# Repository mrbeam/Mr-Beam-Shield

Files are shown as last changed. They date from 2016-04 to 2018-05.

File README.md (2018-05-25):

# README #

### Mr Beam Shield ###

* The Mr Beam Shield is a grbl compatible Arduino Shield which combines 3 stepper motor driver sockets (pololu/stepstick compatible) with a laser diode driver 
* Version 1.1
* 

### How do I get set up? ###

* See manual.pdf in this repository for a detailed description of the shield.

### Who do I talk to? ###

* The Mr Beam Shield was developed for the Mr Beam Laser Cutter Kit, published on Kickstarter May 2014
* get in touch for any purpose: support@mr-beam.org

### LICENSE ###
This work is licensed under the Creative Commons Attribution-NonCommercial-ShareAlike 4.0 International License. 
To view a copy of this license, visit http://creativecommons.org/licenses/by-nc-sa/4.0/.

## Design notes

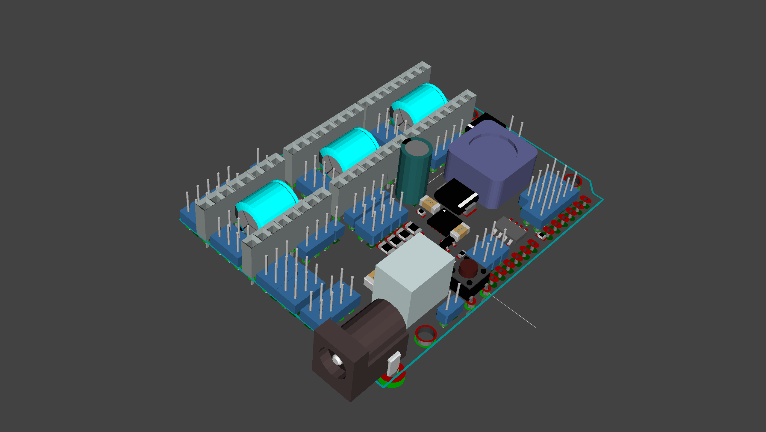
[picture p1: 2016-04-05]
MrBeamShield/MrBeamShield2.png

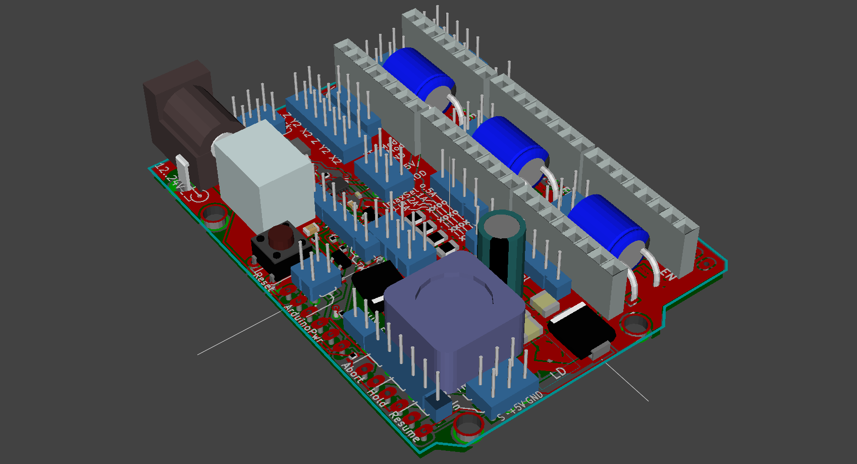
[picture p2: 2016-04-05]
MrBeamShield/MrBeamShield_coil.png

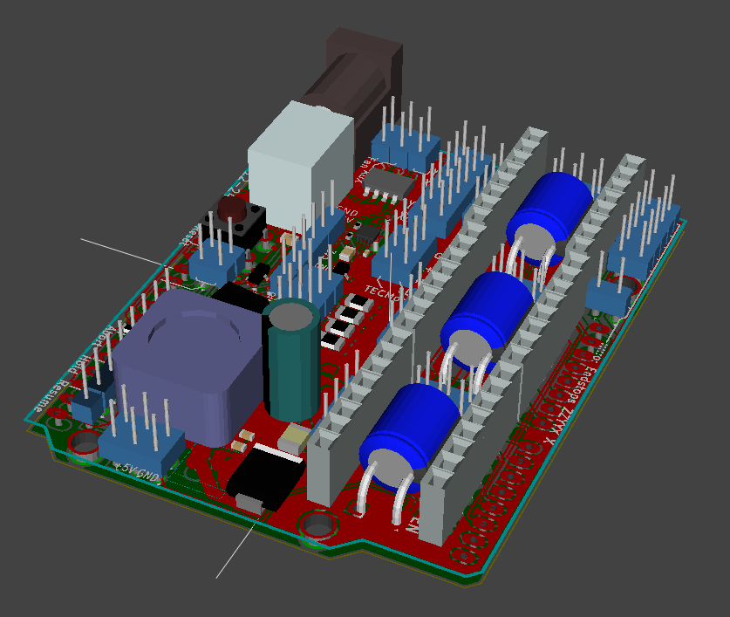
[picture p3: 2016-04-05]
MrBeamShield/MrBeamShield.png

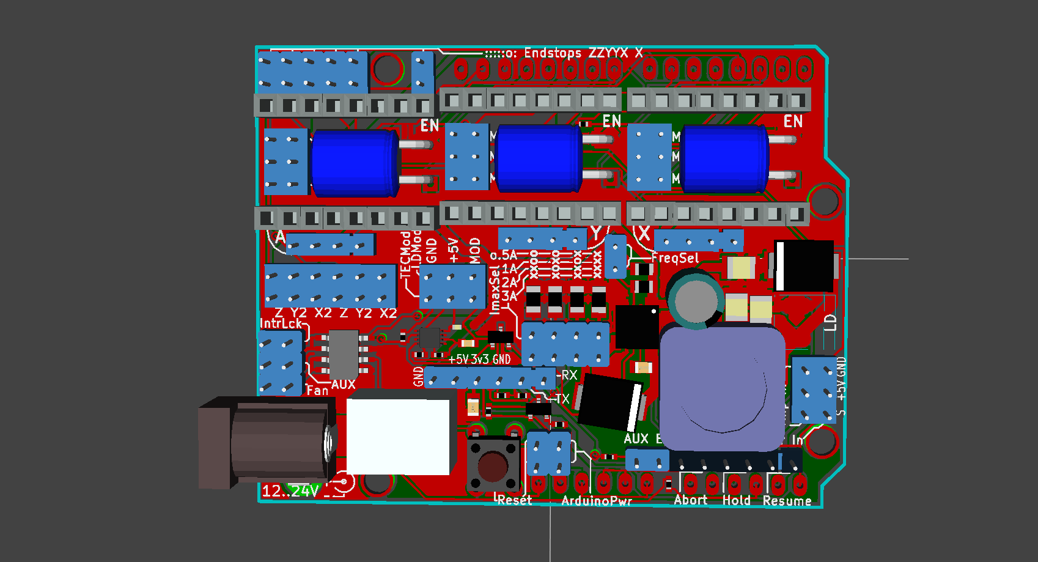
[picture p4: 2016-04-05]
MrBeamShield/MrBeamShield_top.png

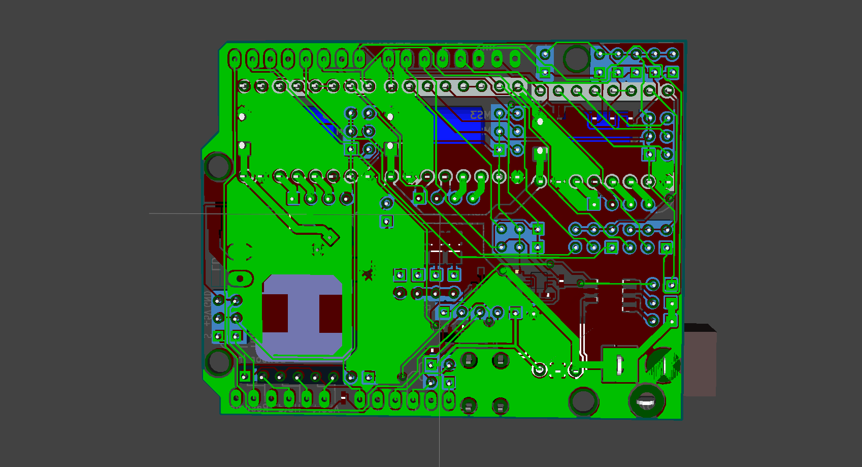
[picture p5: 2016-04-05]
MrBeamShield/MrBeamShield_bottom.png

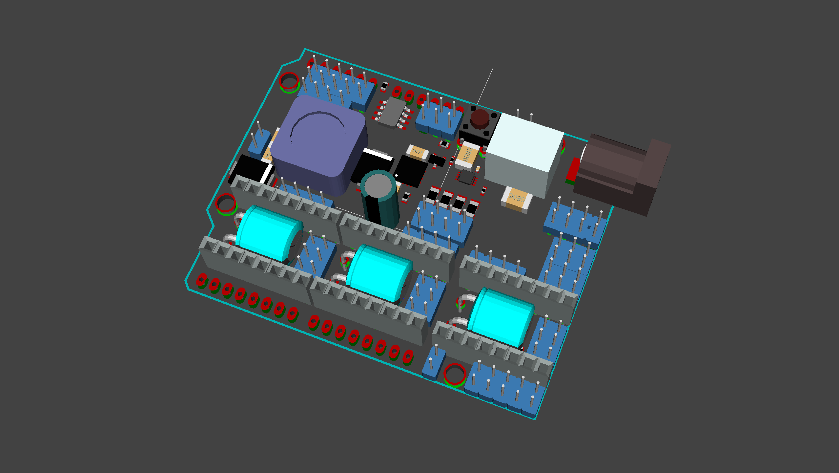
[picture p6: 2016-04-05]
MrBeamShield/MrBeamShield3.png

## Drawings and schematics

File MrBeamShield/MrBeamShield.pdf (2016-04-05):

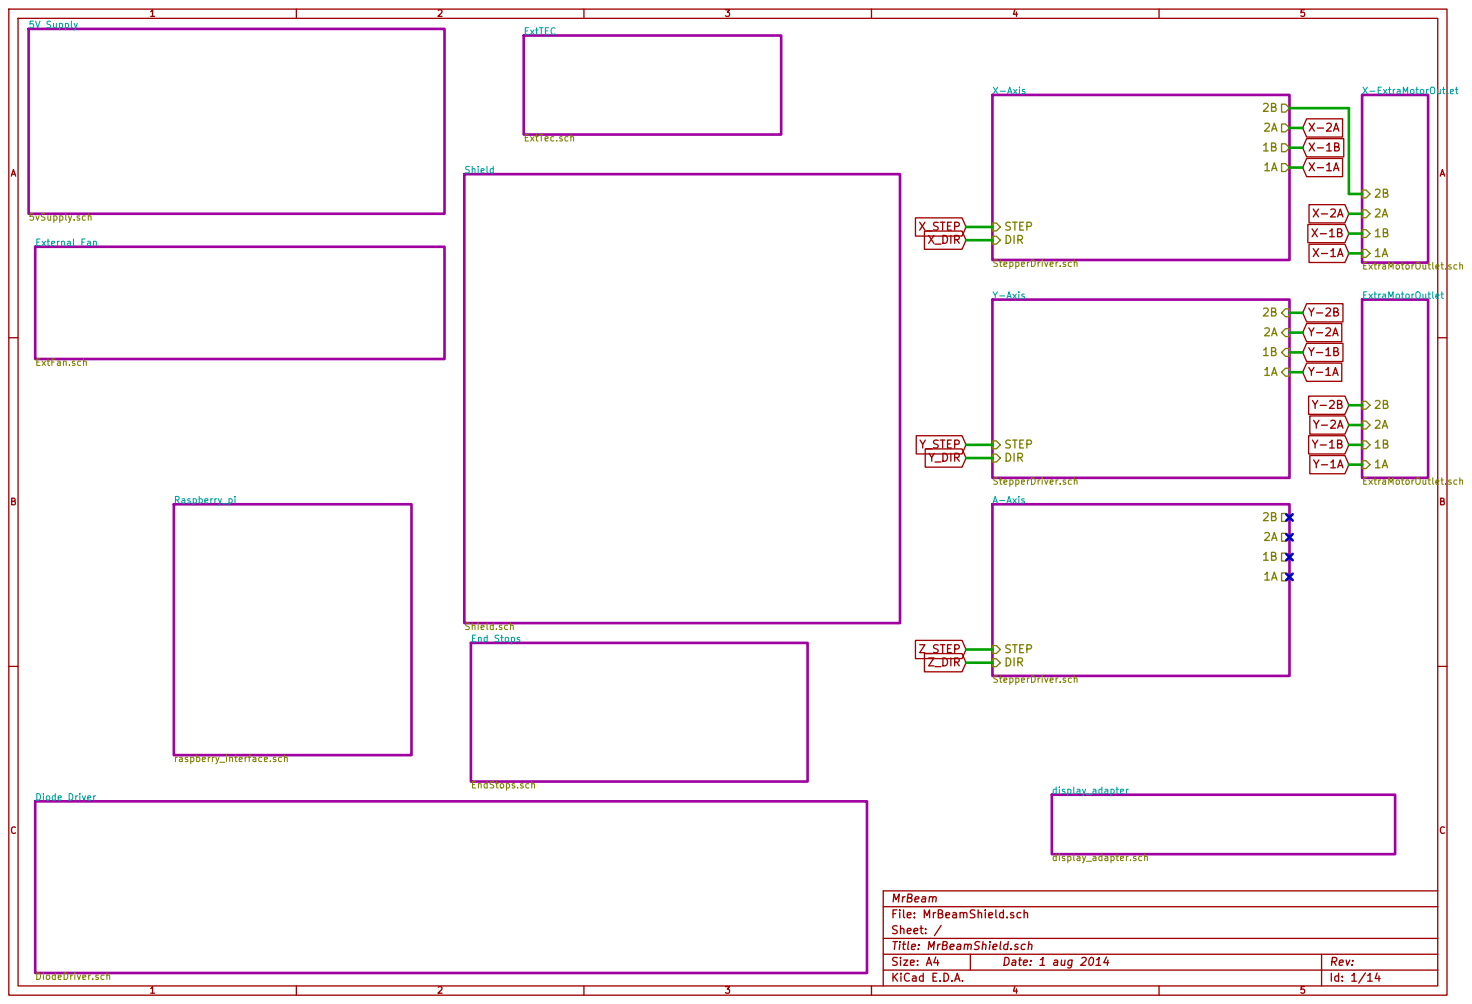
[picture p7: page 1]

ExtTEC
ExtTec.sch Shield Shield.sch

EndStops.sch Diode Driver DiodeDriver.sch

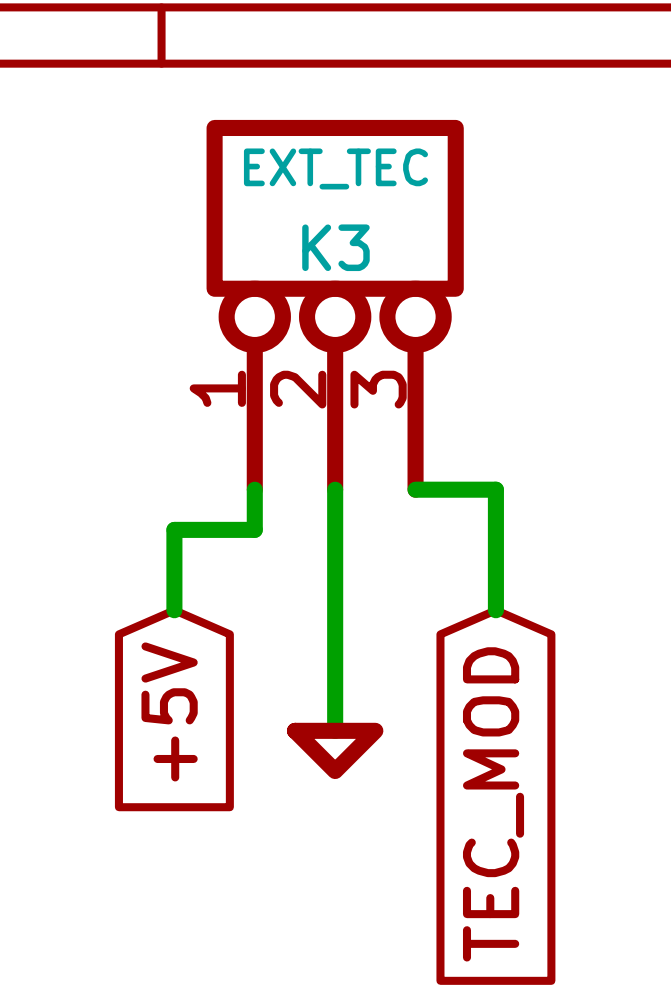
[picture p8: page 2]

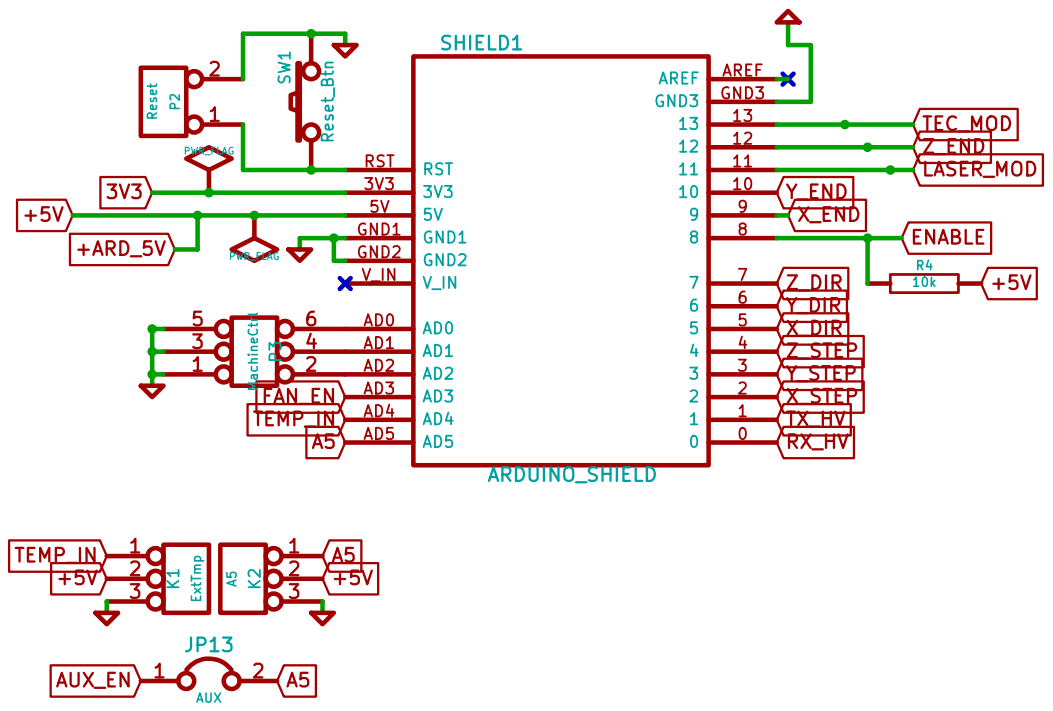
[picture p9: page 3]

Id: 3/14 Title: noname.sch File: Shield.sch
Sheet: /Shield/

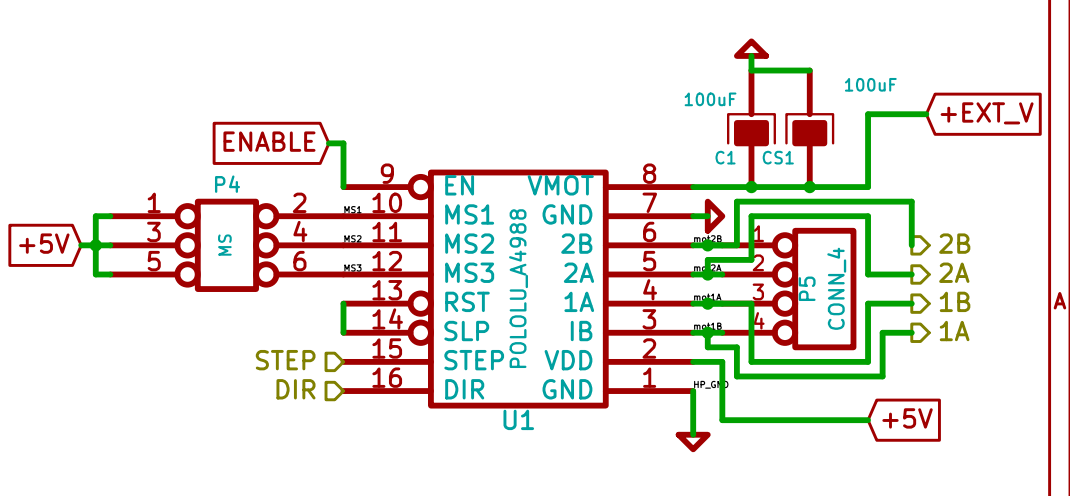
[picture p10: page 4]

Id: 4/14 Title: noname.sch File: StepperDriver.sch
Sheet: /X-Axis/

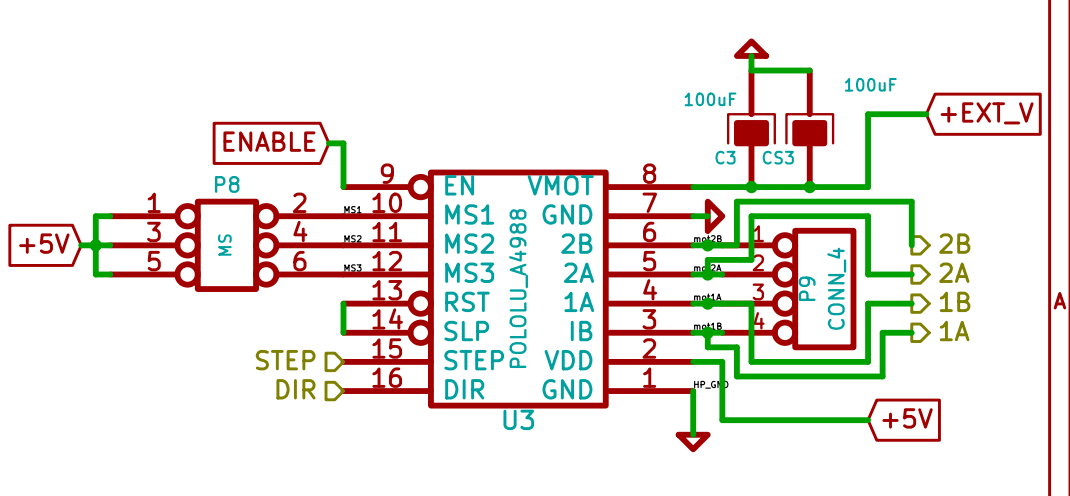
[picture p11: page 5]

Id: 5/14 Title: noname.sch File: StepperDriver.sch
Sheet: /A-Axis/

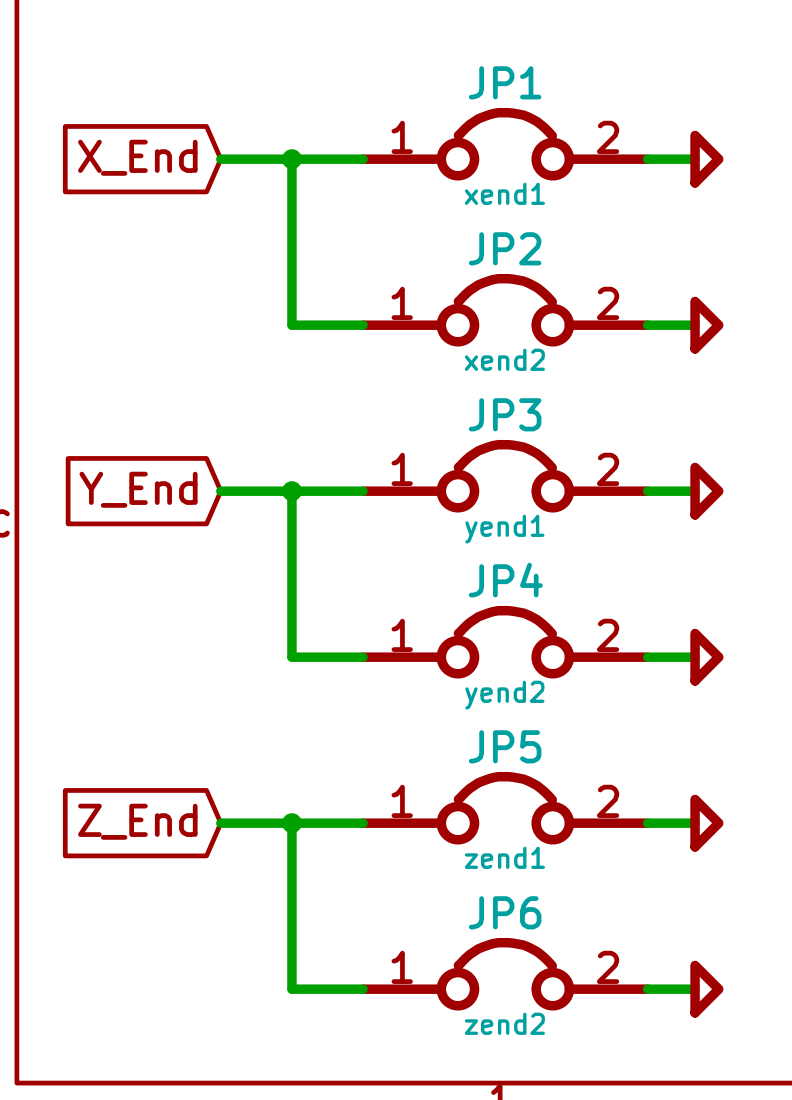
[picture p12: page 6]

Id: 6/14 Title: noname.sch File: EndStops.sch
Sheet: /End Stops/

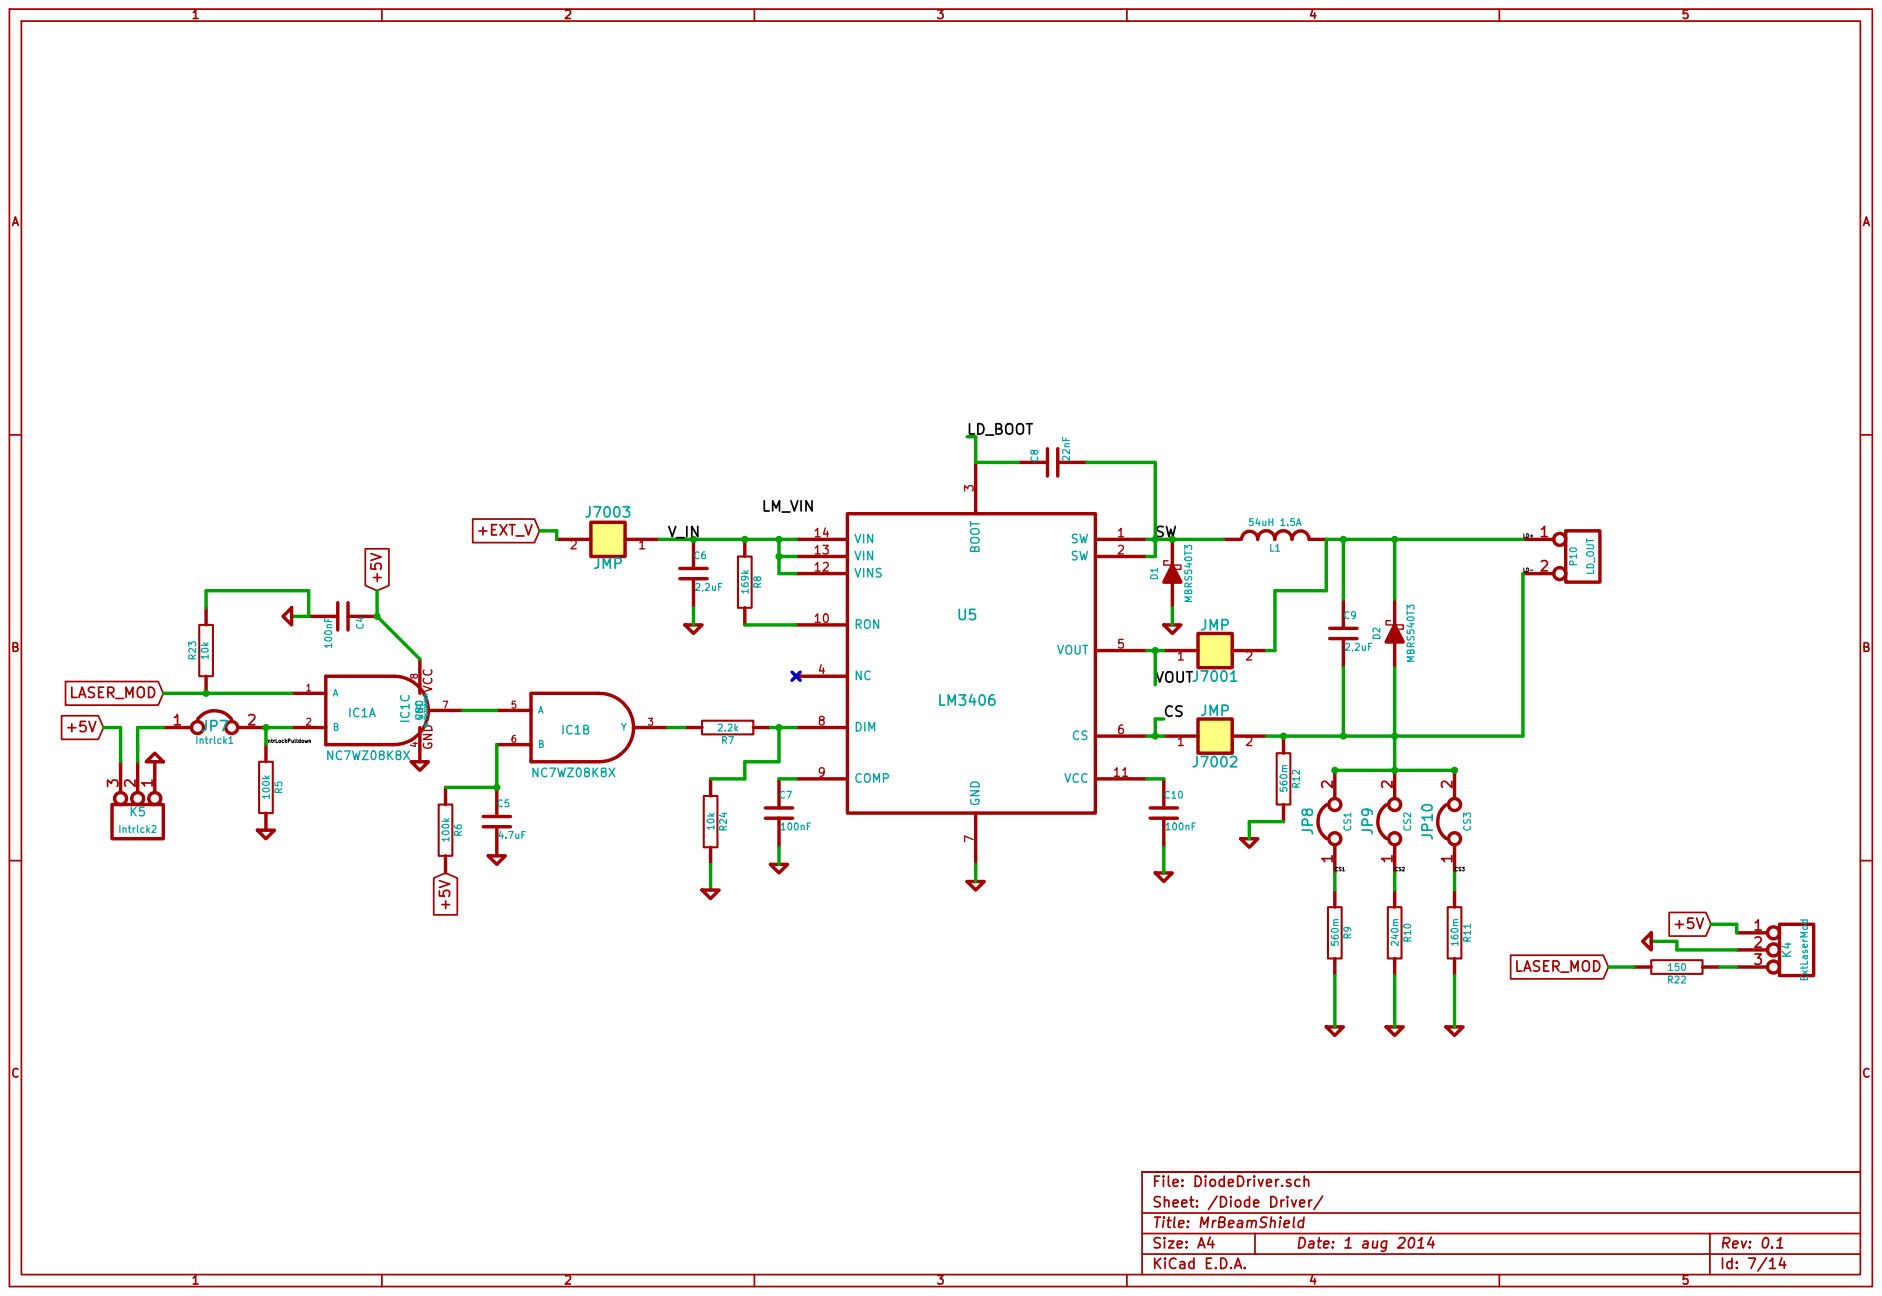
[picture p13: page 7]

3 NC 4 VOUT 5 CS 6 GND

7 DIM 8 COMP 9 RON 10 VCC 11 VINS 12 VIN 13 VIN 14 U5

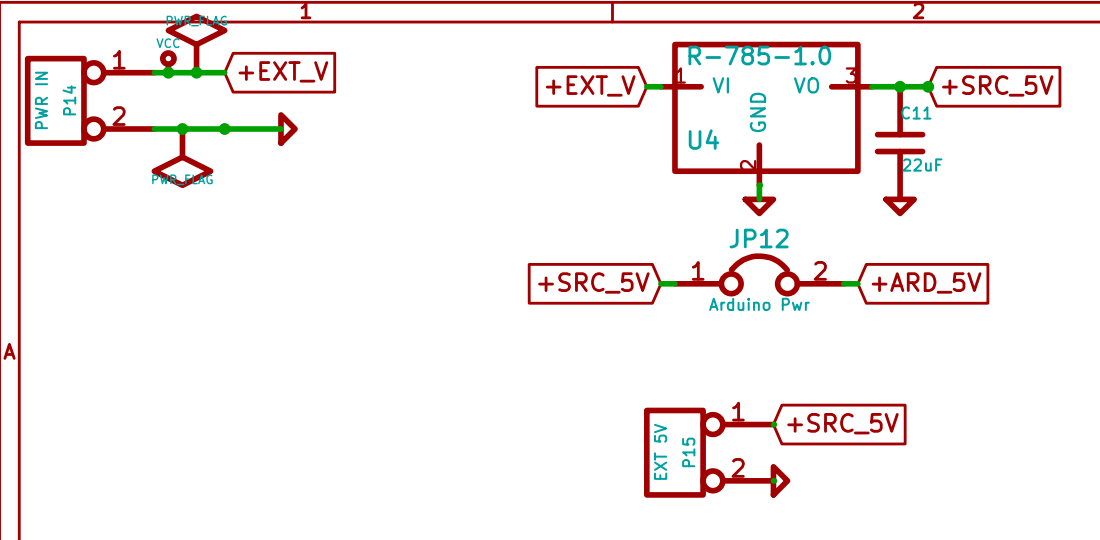
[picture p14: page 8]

Id: 8/14 Title: File: 5vSupply.sch
Sheet: /5V Supply/

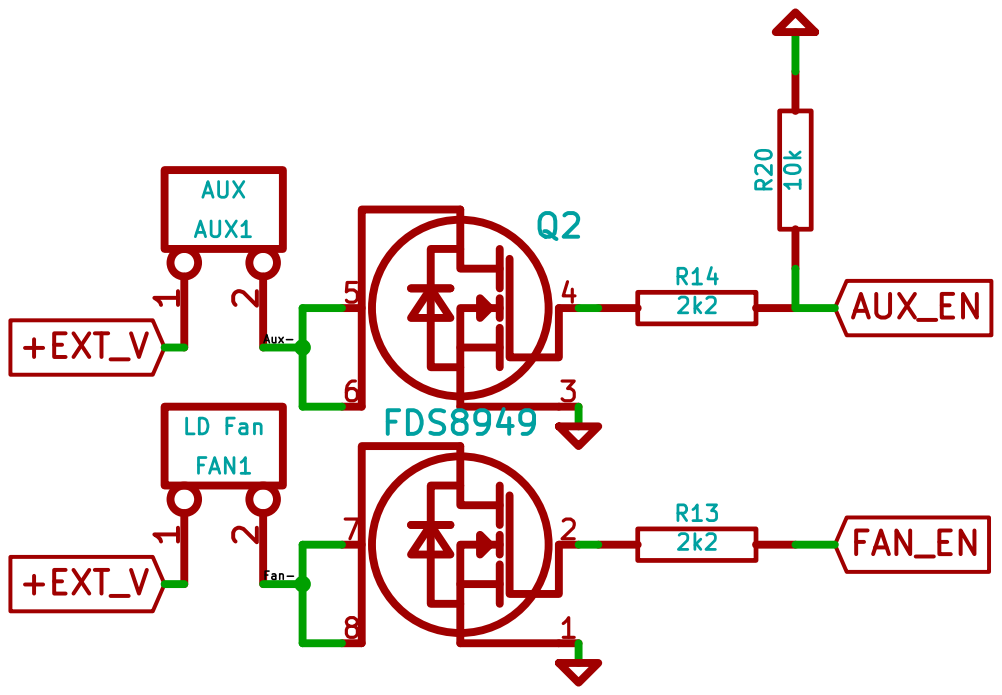
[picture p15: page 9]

Id: 9/14 Title: noname.sch File: ExtFan.sch Sheet: /External Fan/

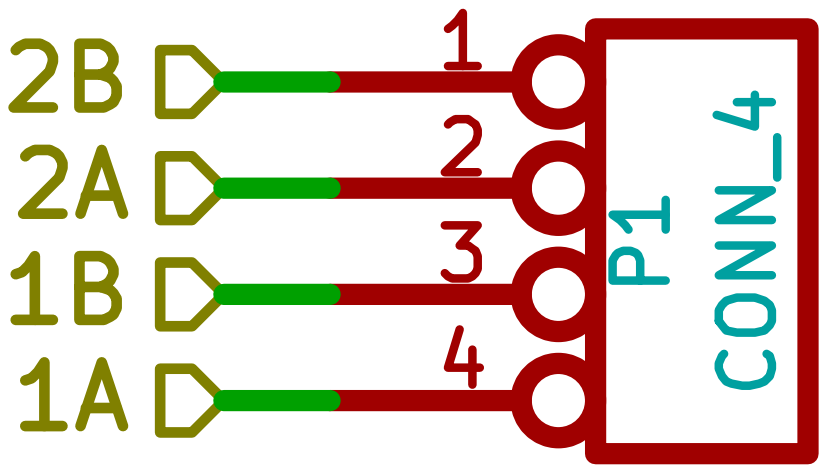
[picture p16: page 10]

Id: 10/14 Title: File: ExtraMotorOutlet.sch
Sheet: /ExtraMotorOutlet/

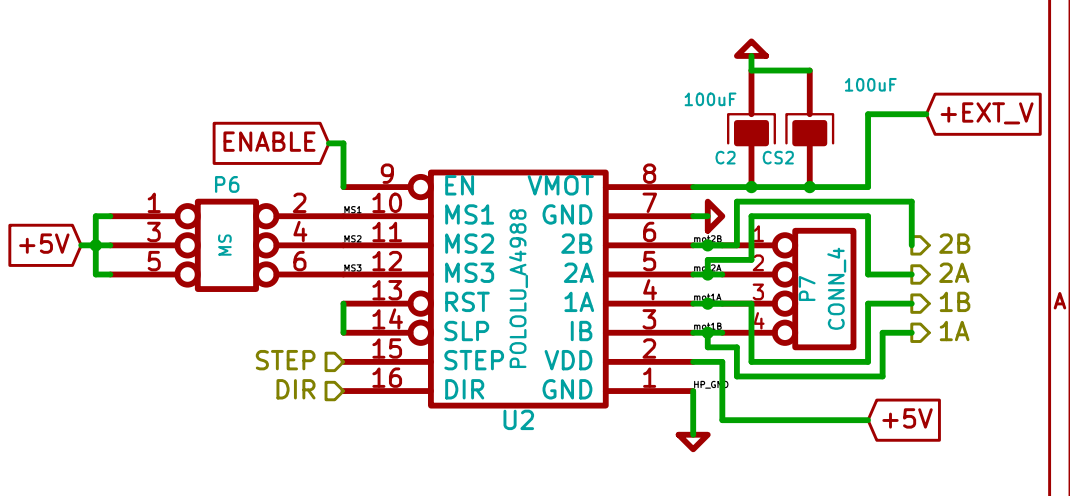
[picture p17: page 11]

Id: 11/14 Title: noname.sch File: StepperDriver.sch
Sheet: /Y-Axis/

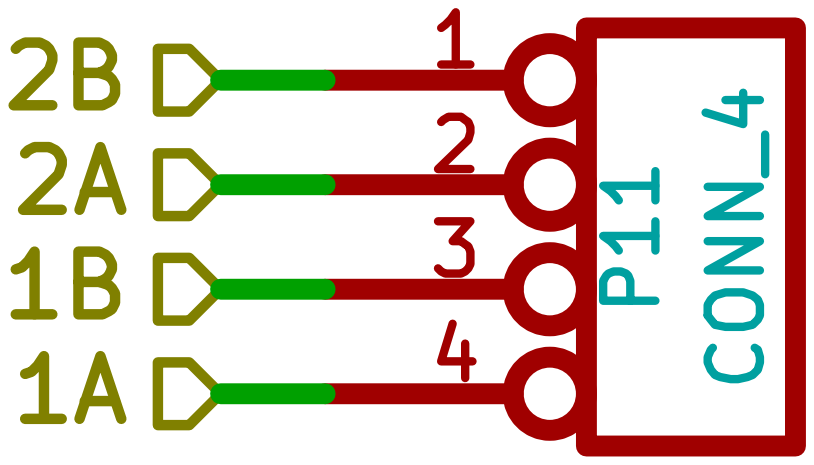
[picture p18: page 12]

Id: 12/14 Title: File: ExtraMotorOutlet.sch
Sheet: /X-ExtraMotorOutlet/


Id: 13/14 Title: File: raspberry_interface.sch
Sheet: /Raspberry_pi/


Id: 14/14 Title: noname.sch File: display_adapter.sch

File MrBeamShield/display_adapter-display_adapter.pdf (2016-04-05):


Id: 14/14 Title: noname.sch File: display_adapter.sch

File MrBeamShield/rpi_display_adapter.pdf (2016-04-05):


Id: 14/14 Title: noname.sch File: display_adapter.sch

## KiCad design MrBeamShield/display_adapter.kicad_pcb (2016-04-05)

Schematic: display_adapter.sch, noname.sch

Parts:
P12: CONN_RPi
P13: CONN_1_8
P17: CONN_9_16
R19, R21: R
RV1: 10K

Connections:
unnamed: P12.6, P13.1, R21.2, RV1.3
unnamed: P13.3, R19.2, R21.1, RV1.2
unnamed: P12.22, P13.4
unnamed: P12.20, P17.8
unnamed: P12.18, P13.6
unnamed: P12.16, P17.3
unnamed: P12.15, P17.6
unnamed: P12.11, P17.4
unnamed: P12.13, P17.5
unnamed: P12.2, P13.2, R19.1, RV1.1
unnamed: P12.4, P17.7
unnamed: P12.14, P13.5

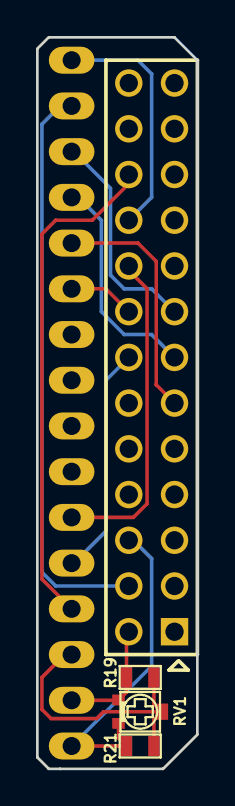
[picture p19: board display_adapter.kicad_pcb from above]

Board: 2 copper layers, 8.9 x 40.6 mm, 6 parts (0 on the bottom side), 12 nets.

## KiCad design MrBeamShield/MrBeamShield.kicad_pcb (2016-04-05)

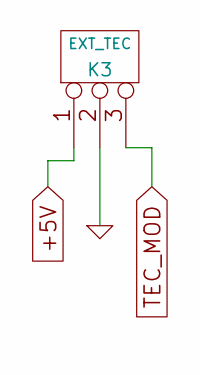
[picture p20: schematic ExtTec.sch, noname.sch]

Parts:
K3: EXT_TEC

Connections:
+5V: K3.1; also elsewhere on the board
GND: K3.2 (PM); also elsewhere on the board
TEC_MOD: K3.3; also elsewhere on the board

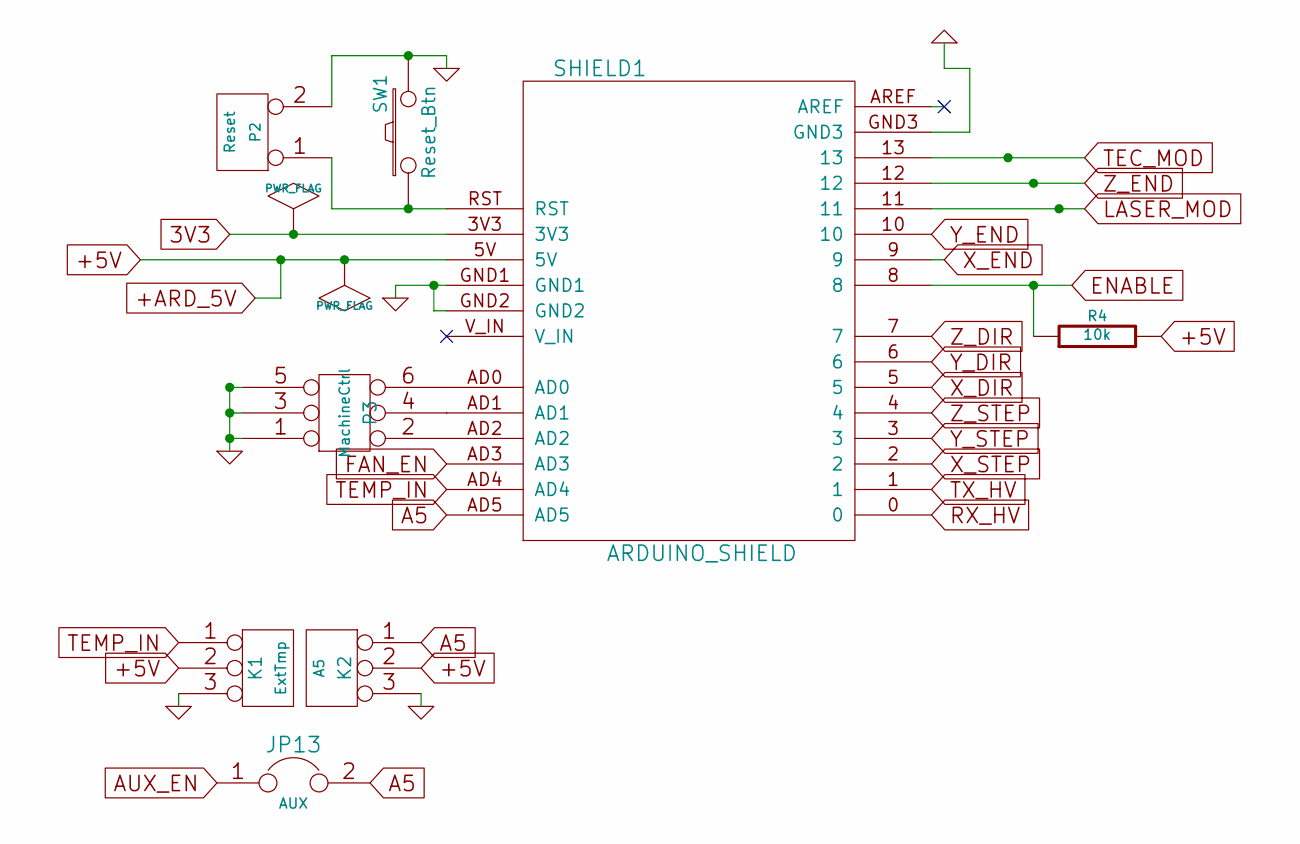
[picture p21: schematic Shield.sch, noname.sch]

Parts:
JP13: AUX
K1: ExtTmp
K2: A5
P2: Reset
P3: MachineCtrl
R4: 10k
SHIELD1: ARDUINO_SHIELD
SW1: Reset_Btn

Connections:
3V3: SHIELD1.3V3; also elsewhere on the board
+5V: K1.2 (PM), K2.2 (PM), R4.2, SHIELD1.5V; also elsewhere on the board
A5: JP13.2, K2.1, SHIELD1.AD5
AUX_EN: JP13.1; also elsewhere on the board
ENABLE: R4.1, SHIELD1.8; also elsewhere on the board
FAN_EN: SHIELD1.AD3; also elsewhere on the board
GND: K1.3, K2.3, P2.2 (PM), P3.1, P3.3, P3.5, SHIELD1.GND1, SHIELD1.GND2, SHIELD1.GND3, SW1.2; also elsewhere on the board
LASER_MOD: SHIELD1.11; also elsewhere on the board
unnamed: P3.2, SHIELD1.AD2
unnamed: P3.4, SHIELD1.AD1
unnamed: P3.6, SHIELD1.AD0
unnamed: P2.1, SHIELD1.RST, SW1.1
RX_HV: SHIELD1.0; also elsewhere on the board
TEC_MOD: SHIELD1.13; also elsewhere on the board
TEMP_IN: K1.1, SHIELD1.AD4
TX_HV: SHIELD1.1; also elsewhere on the board
X_DIR: SHIELD1.5; also elsewhere on the board
X_END: SHIELD1.9; also elsewhere on the board
X_STEP: SHIELD1.2; also elsewhere on the board
Y_DIR: SHIELD1.6; also elsewhere on the board
Y_END: SHIELD1.10; also elsewhere on the board
Y_STEP: SHIELD1.3; also elsewhere on the board
Z_DIR: SHIELD1.7; also elsewhere on the board
Z_END: SHIELD1.12; also elsewhere on the board
Z_STEP: SHIELD1.4; also elsewhere on the board

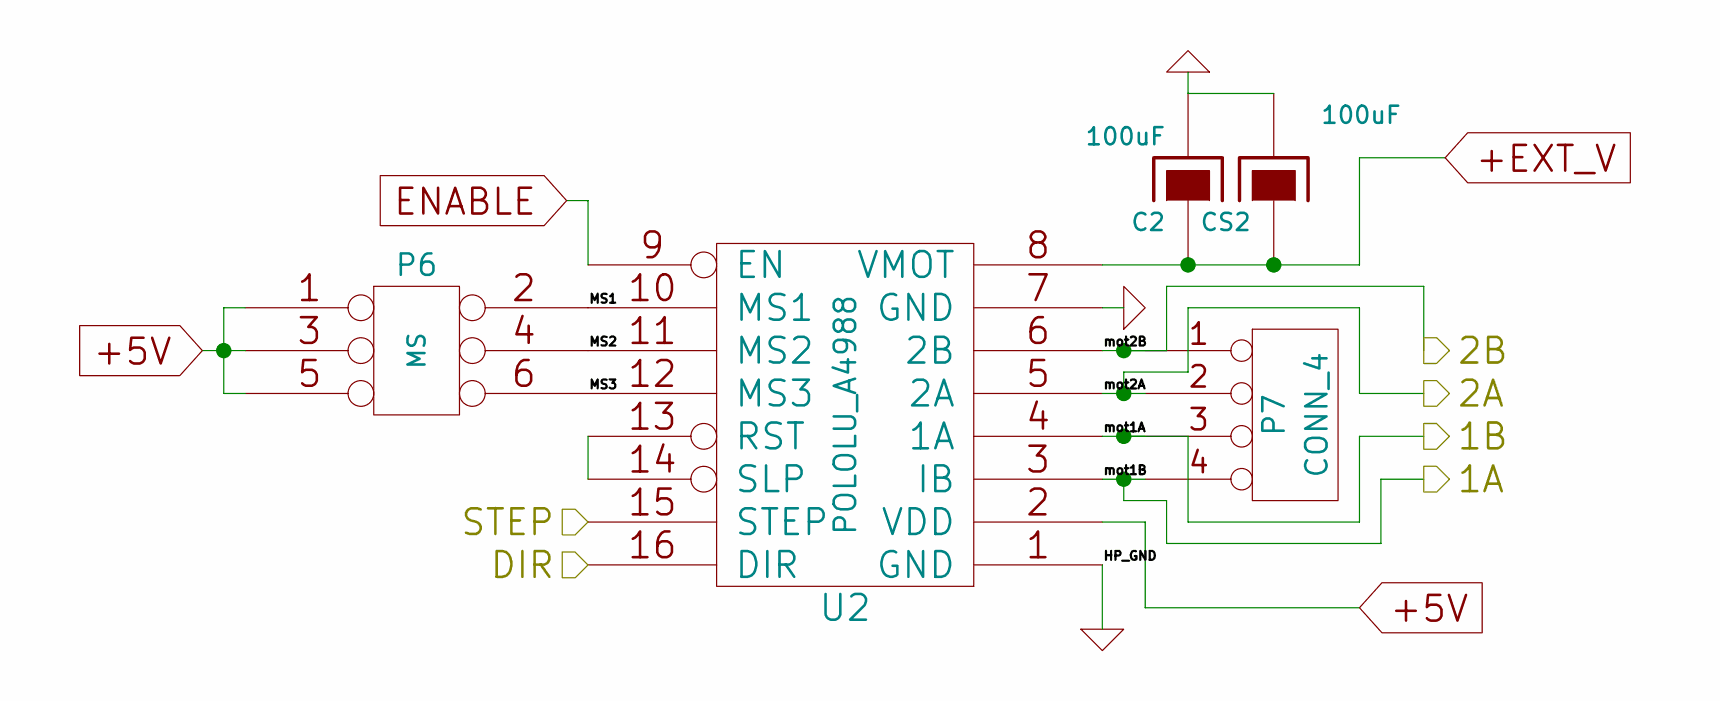
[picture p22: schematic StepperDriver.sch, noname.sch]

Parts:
C1: 100uF
CS3: 100uF
P4: MS
P5: CONN_4
U1: POLOLU_A4988

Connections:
+5V: P4.1, P4.3, P4.5, U1.2 (VDD); also elsewhere on the board
+EXT_V: C1.1, CS3.1, U1.8 (VMOT); also elsewhere on the board
/X-Axis/2B: P5.1, U1.6 (2B); also elsewhere on the board
/X-Axis/MS1: P4.2, U1.10 (MS1)
/X-Axis/MS2: P4.4, U1.11 (MS2)
/X-Axis/MS3: P4.6, U1.12 (MS3)
ENABLE: U1.9 (EN); also elsewhere on the board
GND: C1.2, CS3.2, U1.1 (GND), U1.7 (GND); also elsewhere on the board
unnamed: U1.13 (RST), U1.14 (SLP)
X-1A: P5.4, U1.3 (IB); also elsewhere on the board
X-1B: P5.3, U1.4 (1A); also elsewhere on the board
X-2A: P5.2, U1.5 (2A); also elsewhere on the board
X_DIR: U1.16 (DIR); also elsewhere on the board
X_STEP: U1.15 (STEP); also elsewhere on the board

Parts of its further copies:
C2, C3: 100uF
CS1, CS2: 100uF
P6, P8: MS
P7, P9: CONN_4
U2, U3: POLOLU_A4988

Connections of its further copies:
+5V: P6.1, P6.3, P6.5, P8.1, P8.3, P8.5, U2.2 (VDD), U3.2 (VDD); also elsewhere on the board
+EXT_V: C2.1, C3.1, CS1.1, CS2.1, U2.8 (VMOT), U3.8 (VMOT); also elsewhere on the board
/A-Axis/1A: P9.4, U3.3 (IB)
/A-Axis/1B: P9.3, U3.4 (1A)
/A-Axis/2A: P9.2, U3.5 (2A)
/A-Axis/2B: P9.1, U3.6 (2B)
/A-Axis/MS1: P8.2, U3.10 (MS1)
/A-Axis/MS2: P8.4, U3.11 (MS2)
/A-Axis/MS3: P8.6, U3.12 (MS3)
/Y-Axis/MS1: P6.2, U2.10 (MS1)
/Y-Axis/MS2: P6.4, U2.11 (MS2)
/Y-Axis/MS3: P6.6, U2.12 (MS3)
ENABLE: U2.9 (EN), U3.9 (EN); also elsewhere on the board
GND: C2.2, C3.2, CS1.2, CS2.2, U2.1 (GND), U2.7 (GND), U3.1 (GND), U3.7 (GND); also elsewhere on the board
unnamed: U2.13 (RST), U2.14 (SLP)
unnamed: U3.13 (RST), U3.14 (SLP)
Y-1A: P7.4, U2.3 (IB); also elsewhere on the board
Y-1B: P7.3, U2.4 (1A); also elsewhere on the board
Y-2A: P7.2, U2.5 (2A); also elsewhere on the board
Y-2B: P7.1, U2.6 (2B); also elsewhere on the board
Y_DIR: U2.16 (DIR); also elsewhere on the board
Y_STEP: U2.15 (STEP); also elsewhere on the board
Z_DIR: U3.16 (DIR); also elsewhere on the board
Z_STEP: U3.15 (STEP); also elsewhere on the board

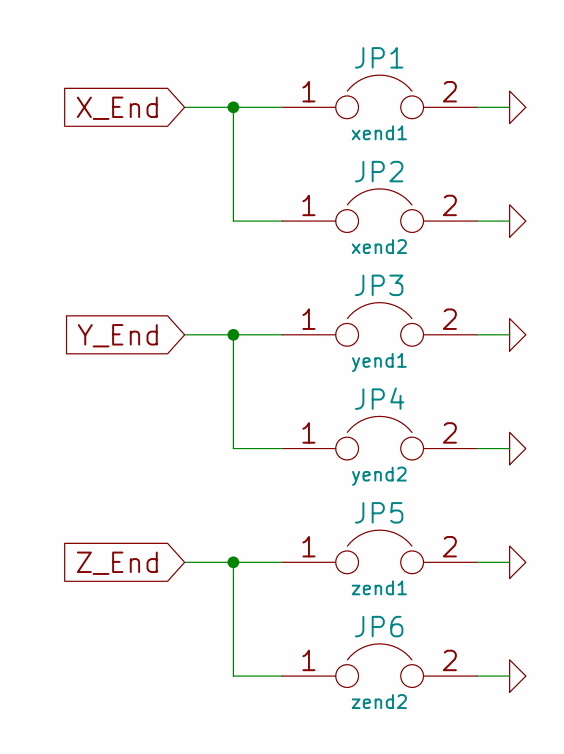
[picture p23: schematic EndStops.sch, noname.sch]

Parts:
JP1: xend1
JP2: xend2
JP3: yend1
JP4: yend2
JP5: zend1
JP6: zend2

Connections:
GND: JP1.2, JP2.2, JP3.2, JP4.2, JP5.2, JP6.2; also elsewhere on the board
X_END: JP1.1, JP2.1; also elsewhere on the board
Y_END: JP3.1, JP4.1; also elsewhere on the board
Z_END: JP5.1, JP6.1; also elsewhere on the board

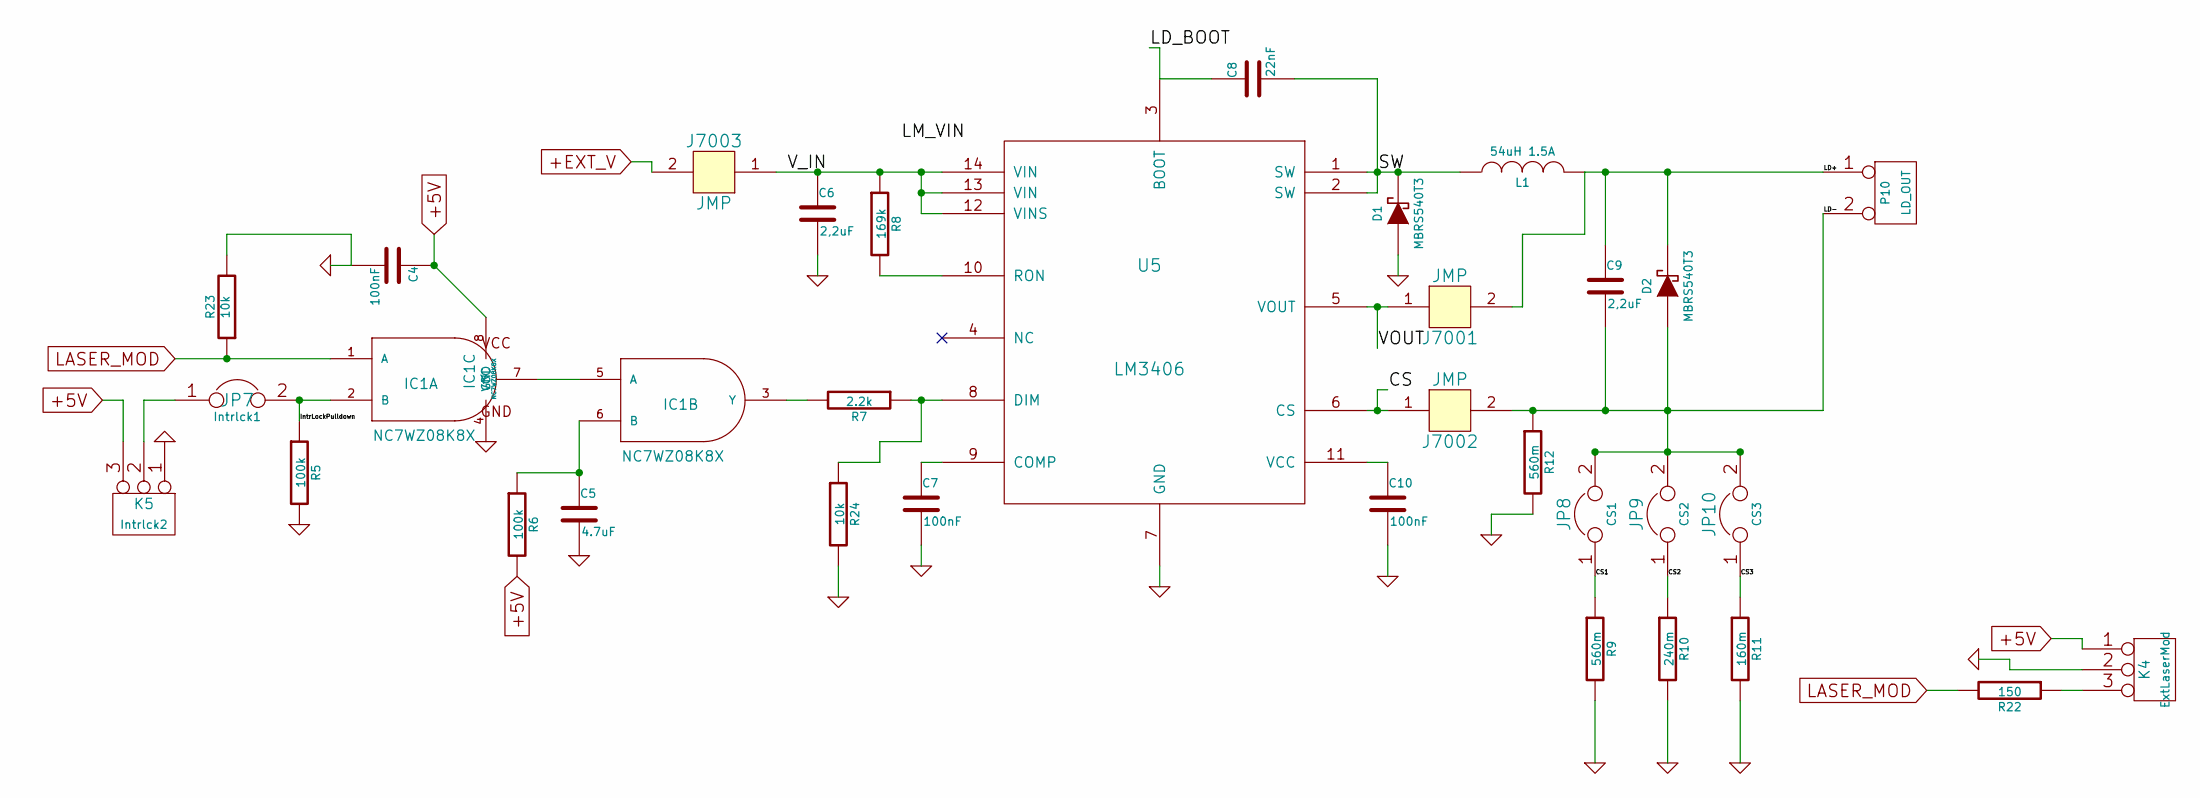
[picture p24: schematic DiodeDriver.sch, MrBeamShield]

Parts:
C4: 100nF
C5: 4.7uF
C6: 2,2uF
C7, C10: 100nF
C8: 22nF
C9: 2,2uF
D1, D2: MBRS540T3
IC1: NC7WZ08K8X; fairchild-tinylogic-TSSOP50P310X90-8N_MAB08A_US8
J7001, J7002, J7003: JMP; 2MM
JP7: Intrlck1
JP8: CS1
JP9: CS2
JP10: CS3
K4: ExtLaserMod
K5: Intrlck2
L1: 54uH 1.5A
P10: LD_OUT
R5, R6: 100k
R7: 2.2k
R8: 169k
R9: 560m
R10: 240m
R11: 160m
R12: 560m
R22: 150
R23, R24: 10k
U5: LM3406

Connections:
+5V: C4.1, IC1.8 (VCC), K4.1, K5.3, R6.2; also elsewhere on the board
+EXT_V: J7003.2; also elsewhere on the board
/Diode Driver/CS: J7002.1, U5.6 (CS)
/Diode Driver/CS1: JP8.1, R9.1
/Diode Driver/CS2: JP9.1, R10.1
/Diode Driver/CS3: JP10.1, R11.1
/Diode Driver/IntrLockPulldown: IC1.2 (B), JP7.2, R5.1
/Diode Driver/LD+: C9.1, D2.2 (K), J7001.2, L1.2, P10.1
/Diode Driver/LD-: C9.2, D2.1 (A), J7002.2, JP8.2, JP9.2, JP10.2, P10.2 (PM), R12.1
/Diode Driver/LD_BOOT: C8.1, U5.3 (BOOT)
/Diode Driver/SW: C8.2, D1.2 (K), L1.1, U5.1 (SW), U5.2 (SW)
/Diode Driver/VOUT: J7001.1, U5.5 (VOUT)
/Diode Driver/V_IN: C6.1, J7003.1, R8.1, U5.12 (VINS), U5.13 (VIN), U5.14 (VIN)
GND: C4.2, C5.2, C6.2, C7.2, C10.2, D1.1 (A), IC1.4 (GND), K4.2 (PM), K5.1, R5.2, R9.2, R10.2, R11.2, R12.2, R23.2, R24.2, U5.7 (GND); also elsewhere on the board
LASER_MOD: IC1.1 (A), R22.2, R23.1; also elsewhere on the board
unnamed: C5.1, IC1.6 (B), R6.1
unnamed: IC1.5 (A), IC1.7 (Y)
unnamed: R8.2, U5.10 (RON)
unnamed: JP7.1, K5.2 (PM)
unnamed: R7.1, R24.1, U5.8 (DIM)
unnamed: C7.1, U5.9 (COMP)
unnamed: C10.1, U5.11 (VCC)
unnamed: IC1.3 (Y), R7.2
unnamed: K4.3, R22.1

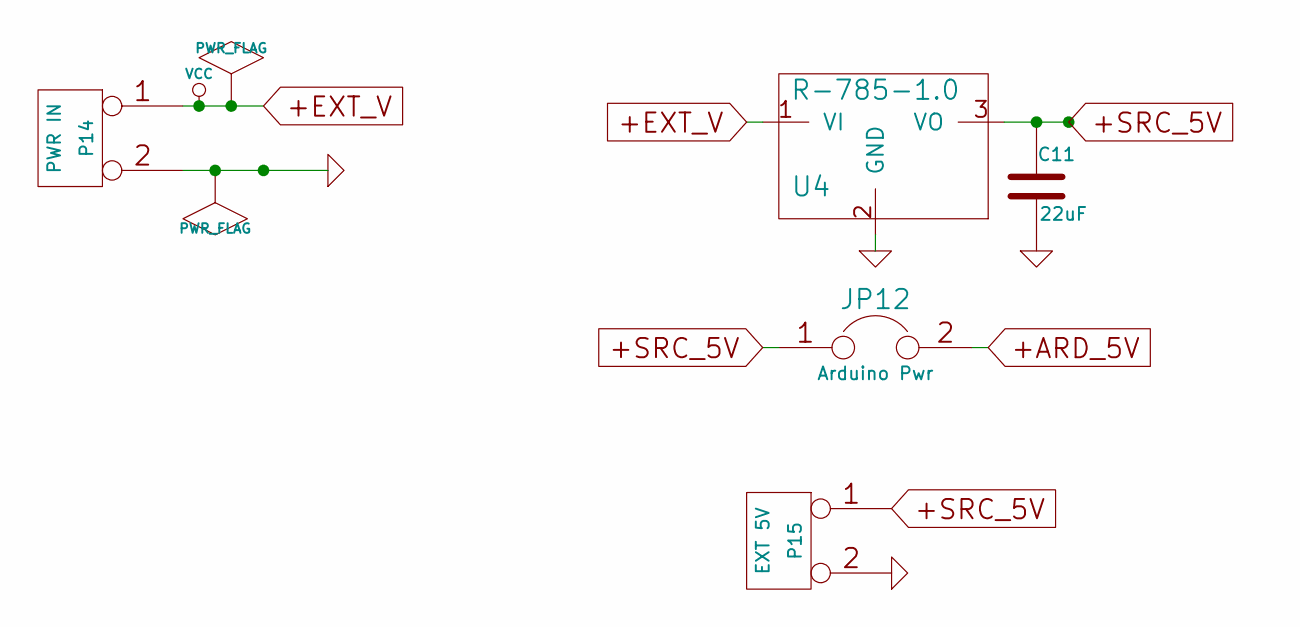
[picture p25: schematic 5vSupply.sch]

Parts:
C11: 22uF
JP12: Arduino Pwr
P14: PWR IN
P15: EXT 5V
U4: R-785-1.0

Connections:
+5V: JP12.2; also elsewhere on the board
+EXT_V: P14.1, U4.1 (VI); also elsewhere on the board
+SRC_5V: C11.1, JP12.1, P15.1, U4.3 (VO)
GND: C11.2, P14.2 (PM), P15.2 (PM), U4.2 (GND); also elsewhere on the board

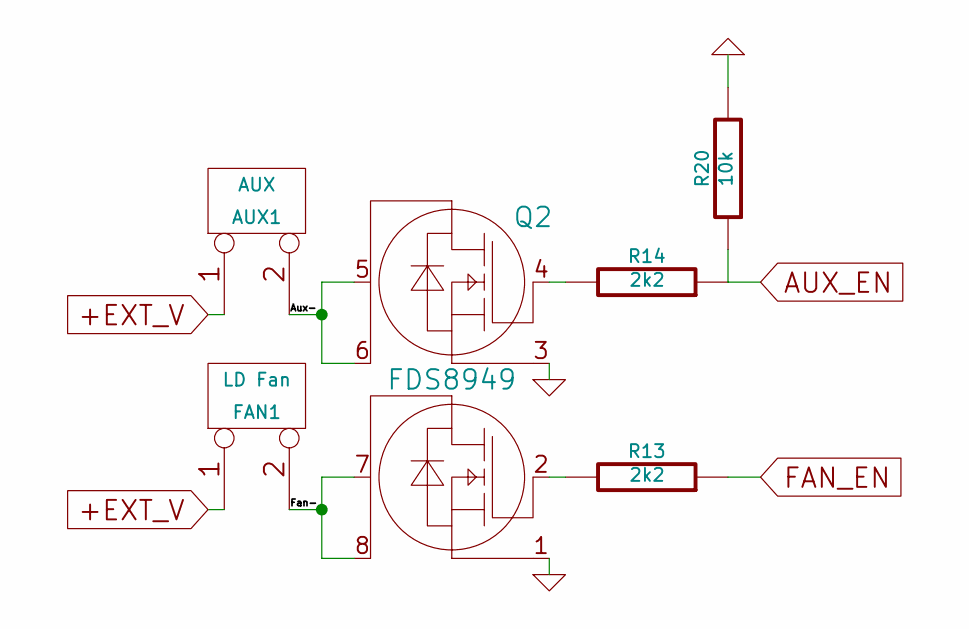
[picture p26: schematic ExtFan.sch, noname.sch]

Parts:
AUX1: AUX
FAN1: LD Fan
Q2: FDS8949
R13, R14: 2k2
R20: 10k

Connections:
+EXT_V: AUX1.1, FAN1.1; also elsewhere on the board
/External Fan/Aux-: AUX1.2 (PM), Q2.5, Q2.6
/External Fan/Fan-: FAN1.2 (PM), Q2.7, Q2.8
AUX_EN: R14.1, R20.1; also elsewhere on the board
FAN_EN: R13.1; also elsewhere on the board
GND: Q2.1, Q2.3, R20.2; also elsewhere on the board
unnamed: Q2.2, R13.2
unnamed: Q2.4, R14.2

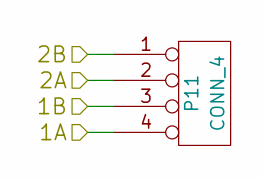
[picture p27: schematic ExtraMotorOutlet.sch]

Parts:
P1: CONN_4

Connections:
Y-1A: P1.4; also elsewhere on the board
Y-1B: P1.3; also elsewhere on the board
Y-2A: P1.2; also elsewhere on the board
Y-2B: P1.1; also elsewhere on the board

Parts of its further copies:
P11: CONN_4

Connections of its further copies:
/X-Axis/2B: P11.1; also elsewhere on the board
X-1A: P11.4; also elsewhere on the board
X-1B: P11.3; also elsewhere on the board
X-2A: P11.2; also elsewhere on the board

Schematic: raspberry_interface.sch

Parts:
P16: Serial
Q3: BSS138; SOT-23
R15, R16, R17: 10k
R18: 20k

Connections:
3V3: P16.3, Q3.1 (G), R15.1; also elsewhere on the board
+5V: R16.1; also elsewhere on the board
GND: R18.1; also elsewhere on the board
RX_HV: Q3.3 (D), R16.2; also elsewhere on the board
RX_LV: P16.2 (PM), Q3.2 (S), R15.2
TX_HV: R17.2; also elsewhere on the board
TX_LV: P16.1, R17.1, R18.2

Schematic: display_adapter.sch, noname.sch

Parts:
P12: CONN_RPi
P13: CONN_1_8
P17: CONN_9_16
R19, R21: R
RV1: 10K

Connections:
unnamed: P12.6, P13.1, R21.2, RV1.3
unnamed: P13.3, R19.2, R21.1, RV1.2
unnamed: P12.22, P13.4
unnamed: P12.20, P17.8
unnamed: P12.18, P13.6
unnamed: P12.16, P17.3
unnamed: P12.15, P17.6
unnamed: P12.11, P17.4
unnamed: P12.13, P17.5
unnamed: P12.2, P13.2, R19.1, RV1.1
unnamed: P12.4, P17.7
unnamed: P12.14, P13.5

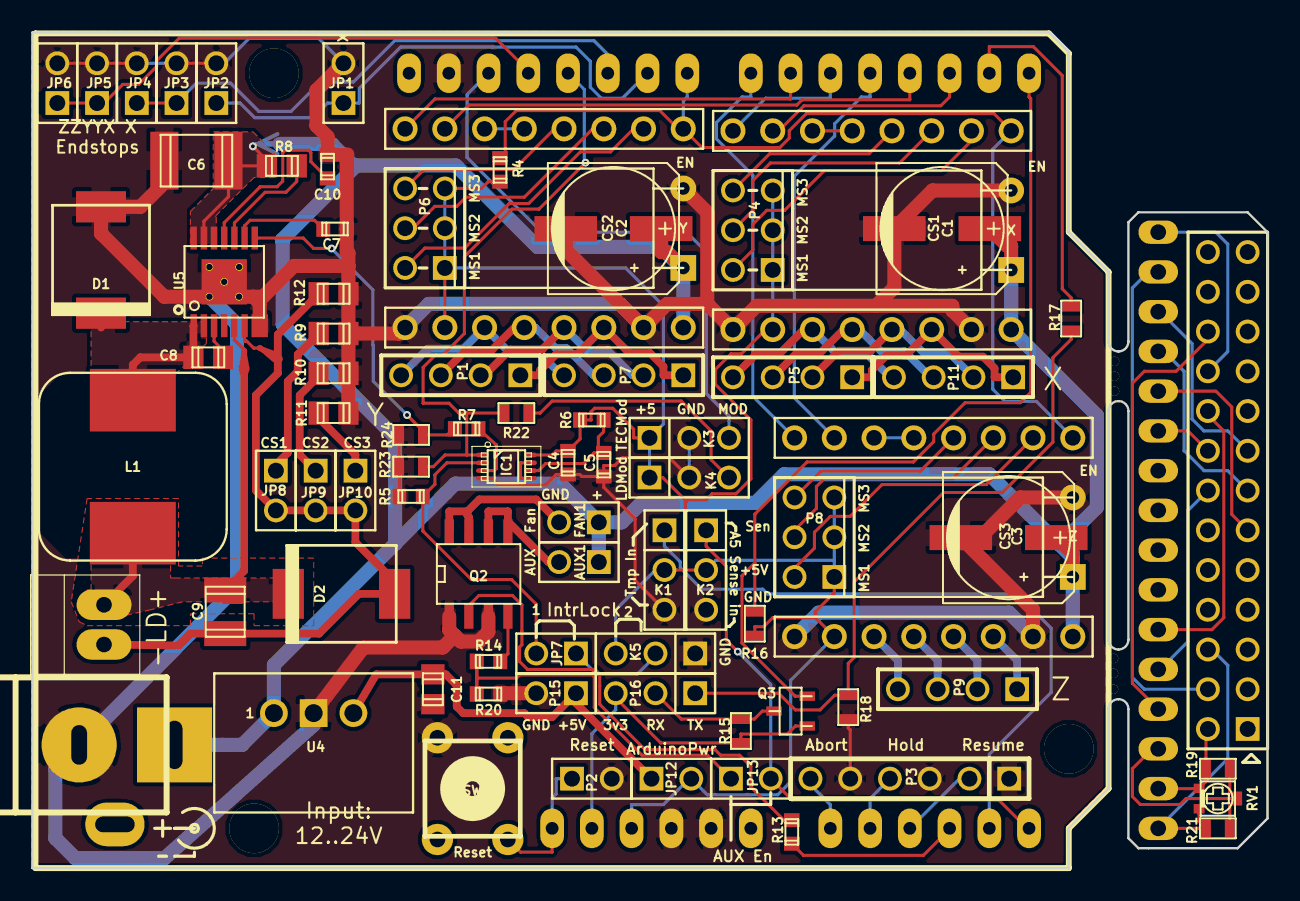
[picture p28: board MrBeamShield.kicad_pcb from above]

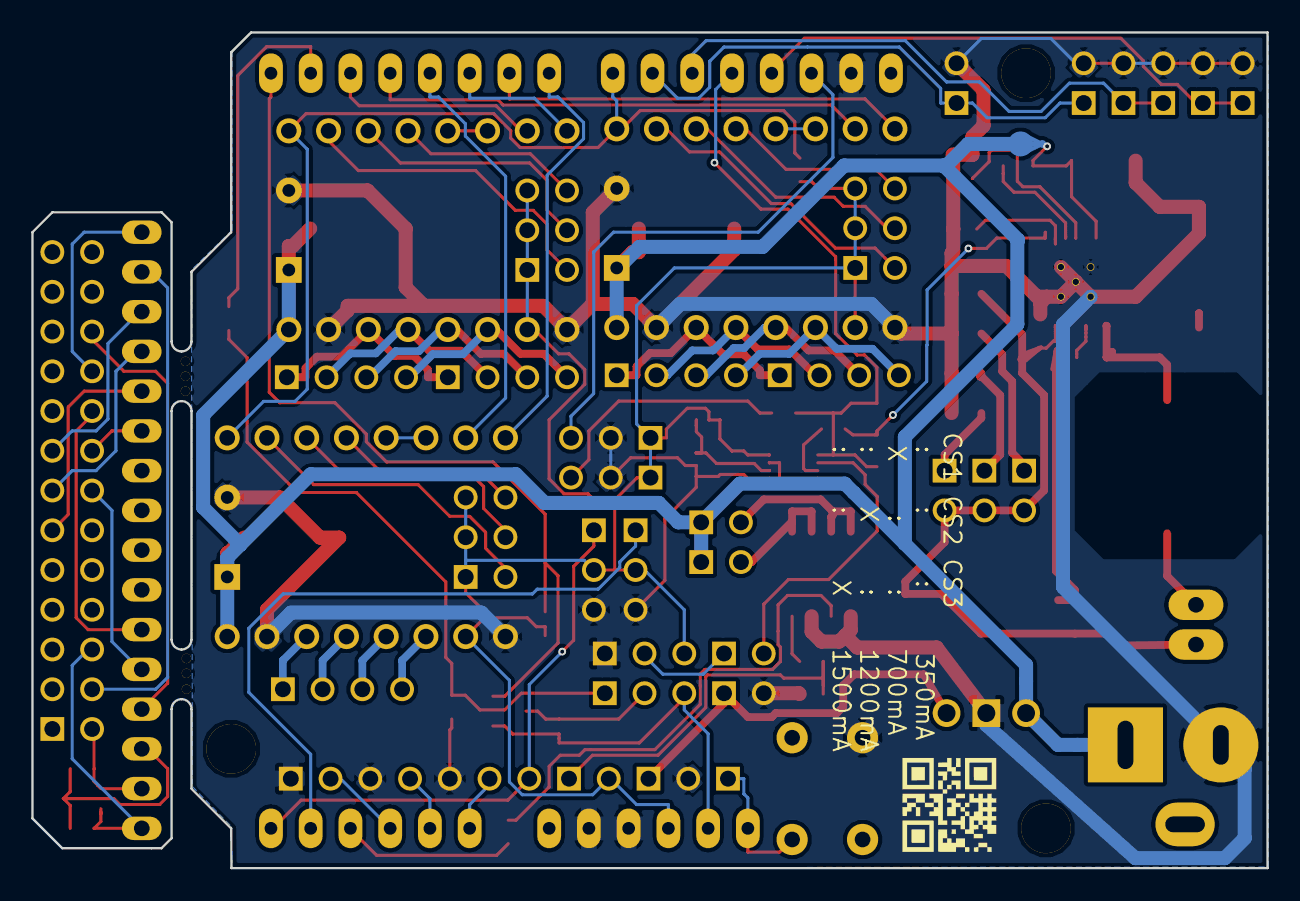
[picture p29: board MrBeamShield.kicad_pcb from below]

Board: 2 copper layers, 78.9 x 53.4 mm, 98 parts (5 on the bottom side), 89 nets.

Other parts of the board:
1PIN1: P776; drill_hole
1PIN2: P775; drill_hole
1PIN3: P774; drill_hole
1PIN4: P771; drill_hole
1PIN5: P772; drill_hole
1PIN6: P773; drill_hole
G_logo_mr: mister_silkscreen-back_10mm
G_logo_oshw: oshw_logo_copper_silkscreen-back_6mm
G_logo_qr: qr_8mm_silkscreen-back_6mm
G_logo_typo: MR_BEAM_INV; MR_BEAM_INV_v2
